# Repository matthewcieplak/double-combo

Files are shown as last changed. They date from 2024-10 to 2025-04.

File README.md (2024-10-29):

# AmpSim

## Author

Extralife Instruments

## Description

Amp sim module for Eurorack using Daisy Patch.

## Programming setup: 

Plug the daisy patch into the PC using USB.

Download and install Zadig. Run it to install the USB driver.

Build and program the device from source in VS code or use the daisy web uploader.

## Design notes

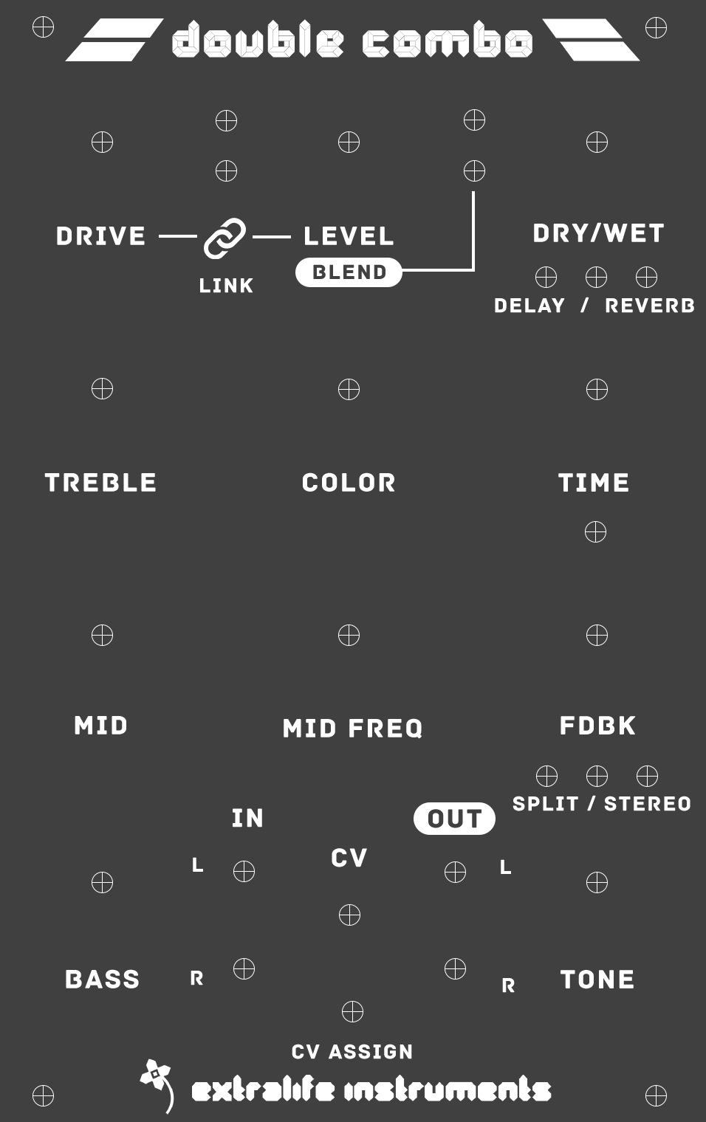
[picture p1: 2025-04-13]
graphics/double_combo.png

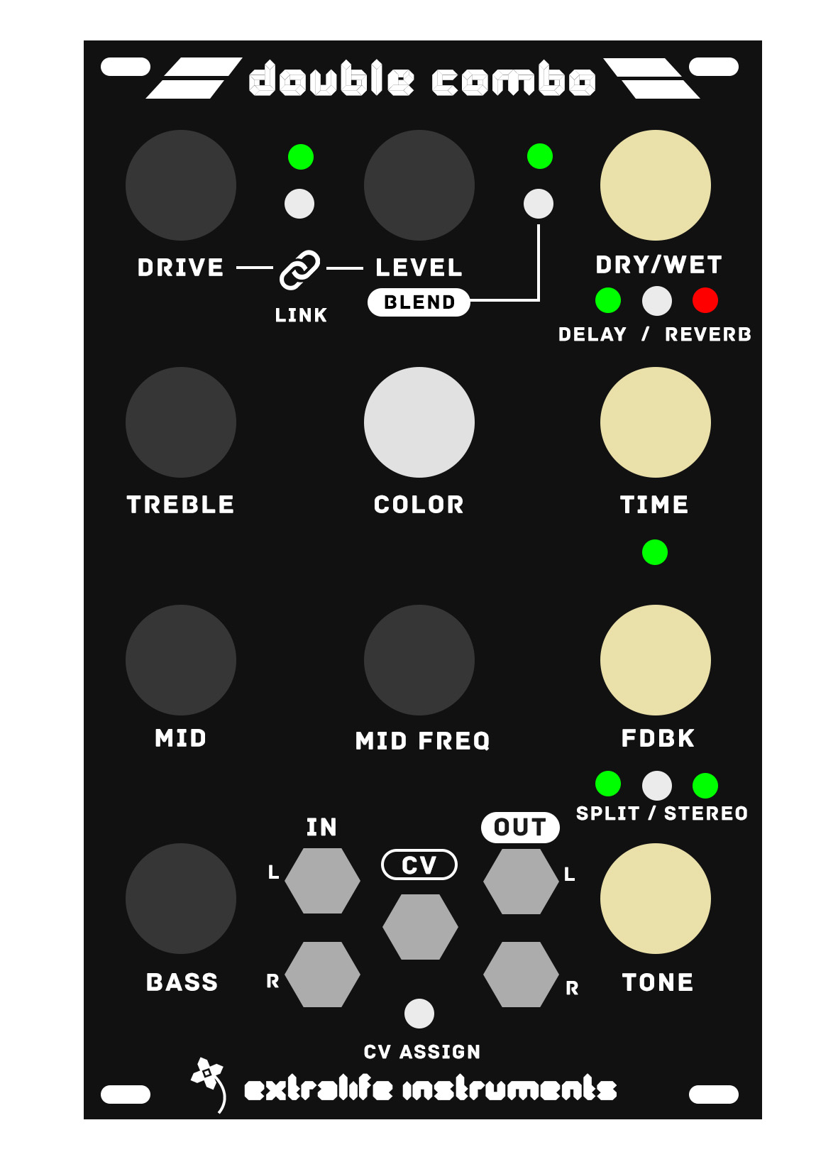
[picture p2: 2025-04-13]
graphics/front panel.jpg

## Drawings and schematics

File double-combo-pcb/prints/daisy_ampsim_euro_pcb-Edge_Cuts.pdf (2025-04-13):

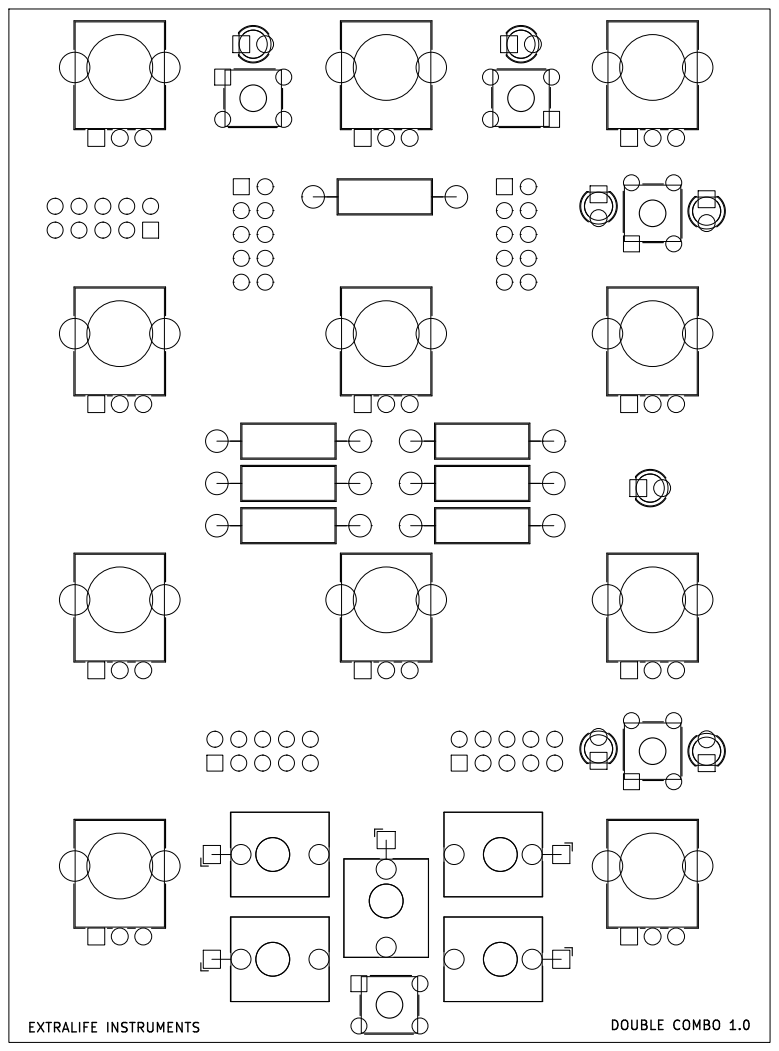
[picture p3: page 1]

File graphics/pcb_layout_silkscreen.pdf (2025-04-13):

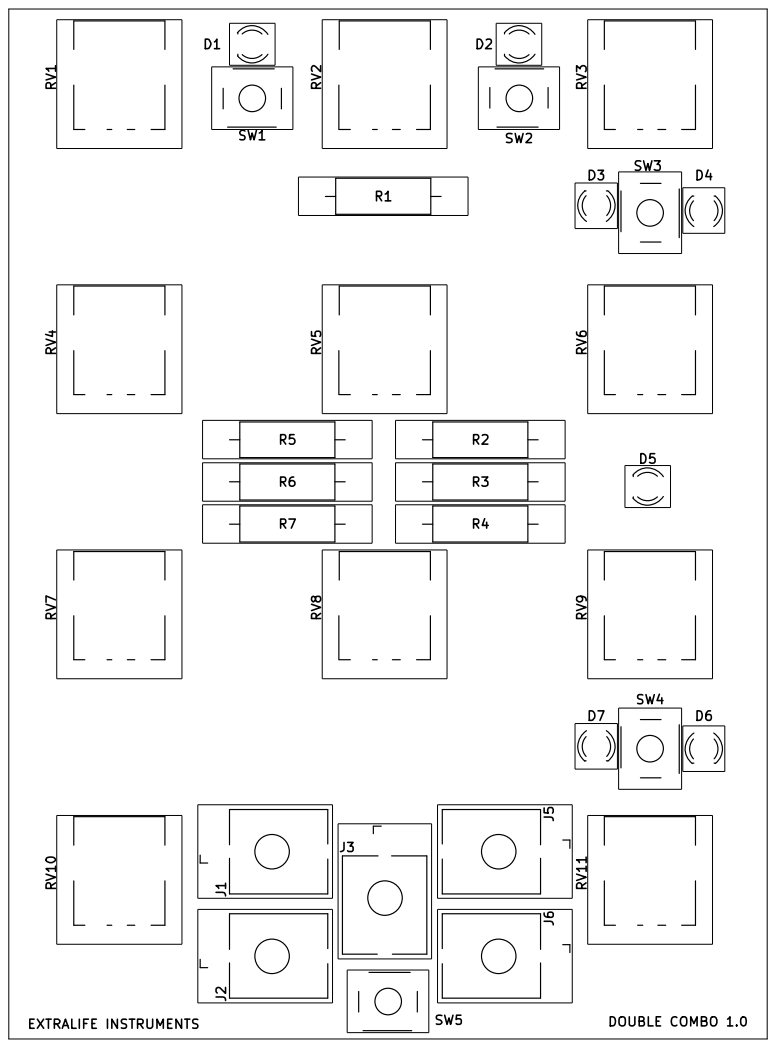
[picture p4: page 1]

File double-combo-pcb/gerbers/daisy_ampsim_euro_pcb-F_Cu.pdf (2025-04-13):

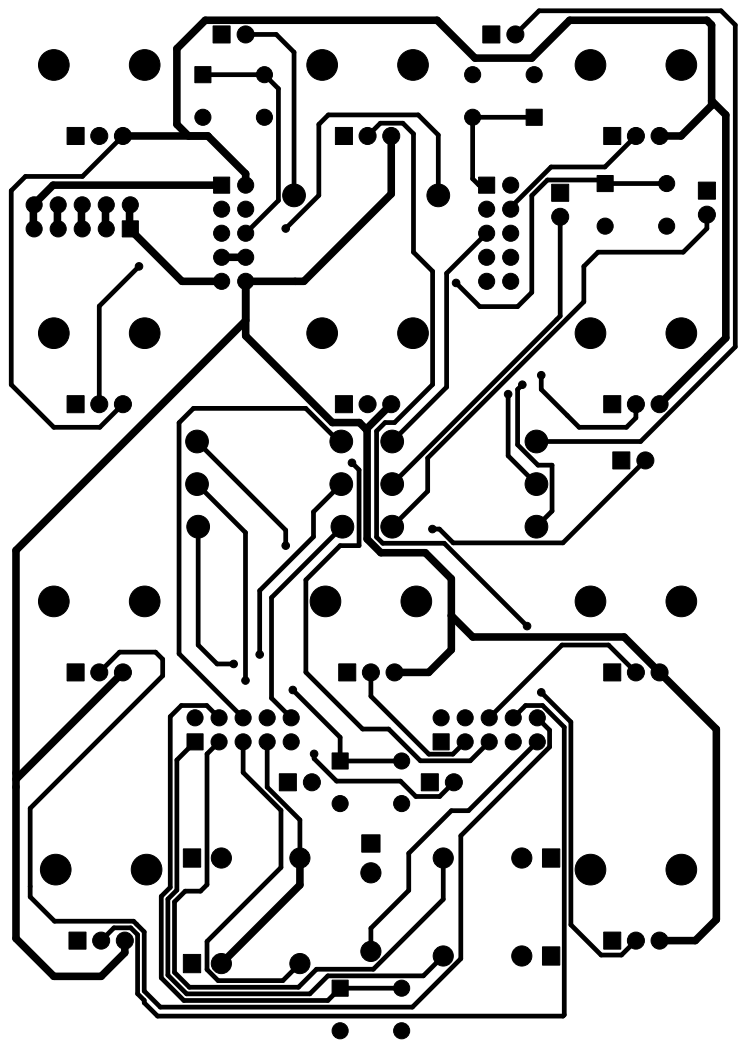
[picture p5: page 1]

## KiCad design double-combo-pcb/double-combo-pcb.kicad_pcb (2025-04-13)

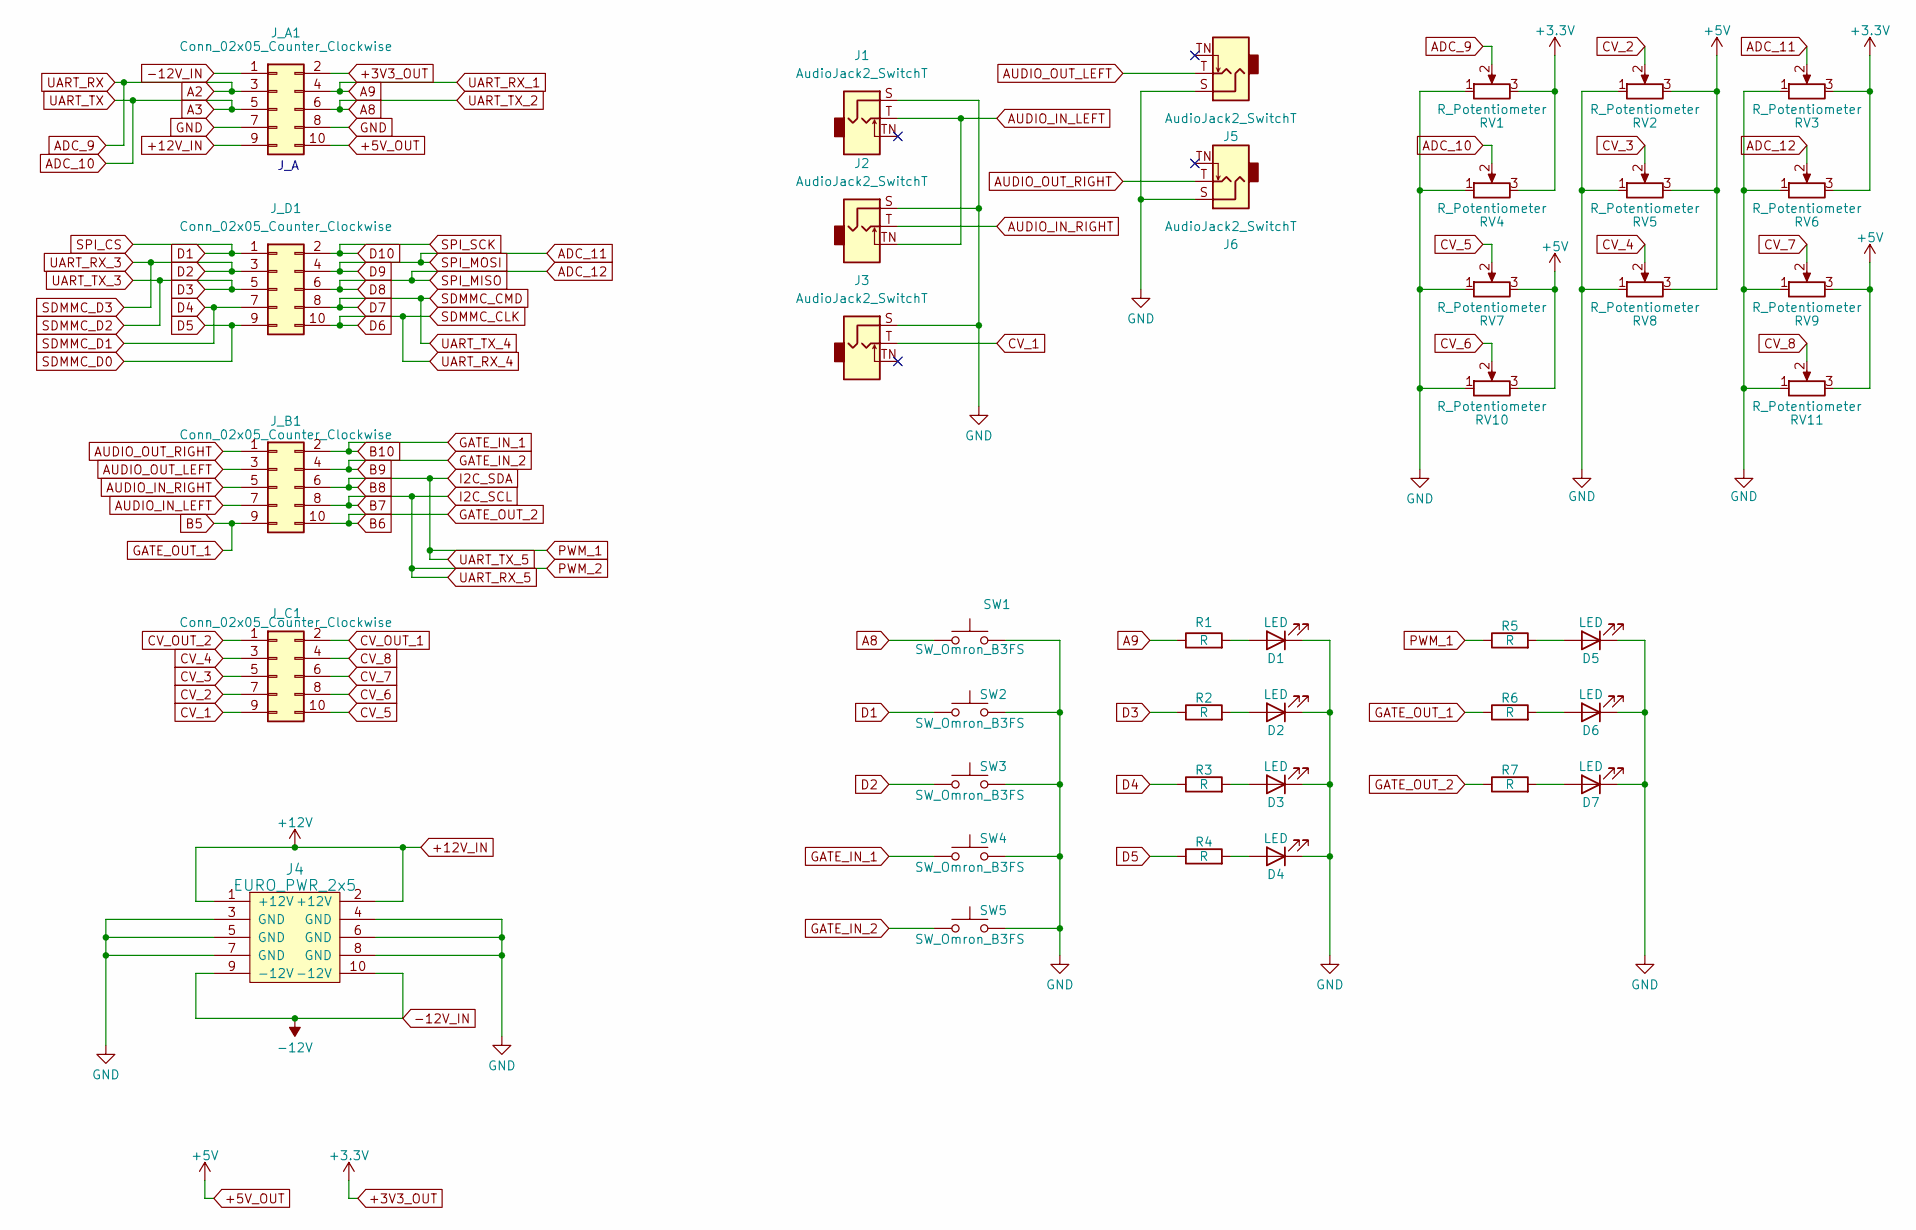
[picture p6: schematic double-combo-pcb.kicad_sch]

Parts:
D1, D2, D3, D4, D5, D6, D7: LED; LED_D3.0mm
J1, J2, J3, J5, J6: AudioJack2_SwitchT; Jack_3.5mm_QingPu_WQP-PJ398SM_Vertical_CircularHoles
J4: EURO_PWR_2x5; PinHeader_2x05_P2.54mm_Vertical
J_A1: Conn_02x05_Counter_Clockwise; PinSocket_2x05_P2.54mm_Vertical
J_B1: Conn_02x05_Counter_Clockwise; PinSocket_2x05_P2.54mm_Vertical
J_C1: Conn_02x05_Counter_Clockwise; PinSocket_2x05_P2.54mm_Vertical
J_D1: Conn_02x05_Counter_Clockwise; PinSocket_2x05_P2.54mm_Vertical
R1, R2, R3, R4, R5, R6, R7: R; R_Axial_DIN0411_L9.9mm_D3.6mm_P15.24mm_Horizontal
RV1, RV2, RV3, RV4, RV5, RV6, RV7, RV8, RV9, RV10, RV11: R_Potentiometer; Potentiometer_Alpha_RD901F-40-00D_Single_Vertical_CircularH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
SW1, SW2, SW3, SW4, SW5: SW_Omron_B3FS; SW_TH_Tactile_Omron_B3F-10xx

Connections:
+3V3_OUT: J_A1.2, RV1.3, RV3.3, RV4.3, RV6.3
+5V_OUT: J_A1.10, RV2.3, RV5.3, RV7.3, RV8.3, RV9.3, RV10.3, RV11.3
+12V_IN: J4.1 (+12V), J4.2 (+12V), J_A1.9
-12V_IN: J4.9 (-12V), J4.10 (-12V), J_A1.1
A2: J_A1.3, RV1.2
A3: J_A1.5, RV4.2
A8: J_A1.6, SW1.1
A9: J_A1.4, R1.1
ADC_11: J_D1.4, RV3.2
ADC_12: J_D1.6, RV6.2
AUDIO_IN_LEFT: J1.T, J2.TN, J_B1.7
AUDIO_IN_RIGHT: J2.T, J_B1.5
AUDIO_OUT_LEFT: J5.T, J_B1.3
AUDIO_OUT_RIGHT: J6.T, J_B1.1
B5: J_B1.9, R6.1
B6: J_B1.10, R7.1
B7: J_B1.8
B8: J_B1.6, R5.1
B9: J_B1.4, SW5.1
B10: J_B1.2, SW4.1
CV_1: J3.T, J_C1.9
CV_2: J_C1.7, RV2.2
CV_3: J_C1.5, RV5.2
CV_4: J_C1.3, RV8.2
CV_5: J_C1.10, RV7.2
CV_6: J_C1.8, RV10.2
CV_7: J_C1.6, RV9.2
CV_8: J_C1.4, RV11.2
CV_OUT_1: J_C1.2
CV_OUT_2: J_C1.1
D1: J_D1.1, SW2.1
D2: J_D1.3, SW3.1
D3: J_D1.5, R2.1
D4: J_D1.7, R3.1
D5: J_D1.9, R4.1
D6: J_D1.10
D7: J_D1.8
D10: J_D1.2
GND: D1.1 (K), D2.1 (K), D3.1 (K), D4.1 (K), D5.1 (K), D6.1 (K), D7.1 (K), J1.S, J2.S, J3.S, J4.3 (GND), J4.4 (GND), J4.5 (GND), J4.6 (GND), J4.7 (GND), J4.8 (GND), J5.S, J6.S, J_A1.7, J_A1.8, RV1.1, RV2.1, RV3.1, RV4.1, RV5.1, RV6.1, RV7.1, RV8.1, RV9.1, RV10.1, RV11.1, SW1.2, SW2.2, SW3.2, SW4.2, SW5.2
unnamed: D1.2 (A), R1.2
unnamed: D2.2 (A), R2.2
unnamed: D3.2 (A), R3.2
unnamed: D4.2 (A), R4.2
unnamed: D5.2 (A), R5.2
unnamed: D6.2 (A), R6.2
unnamed: D7.2 (A), R7.2

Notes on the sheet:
J_A

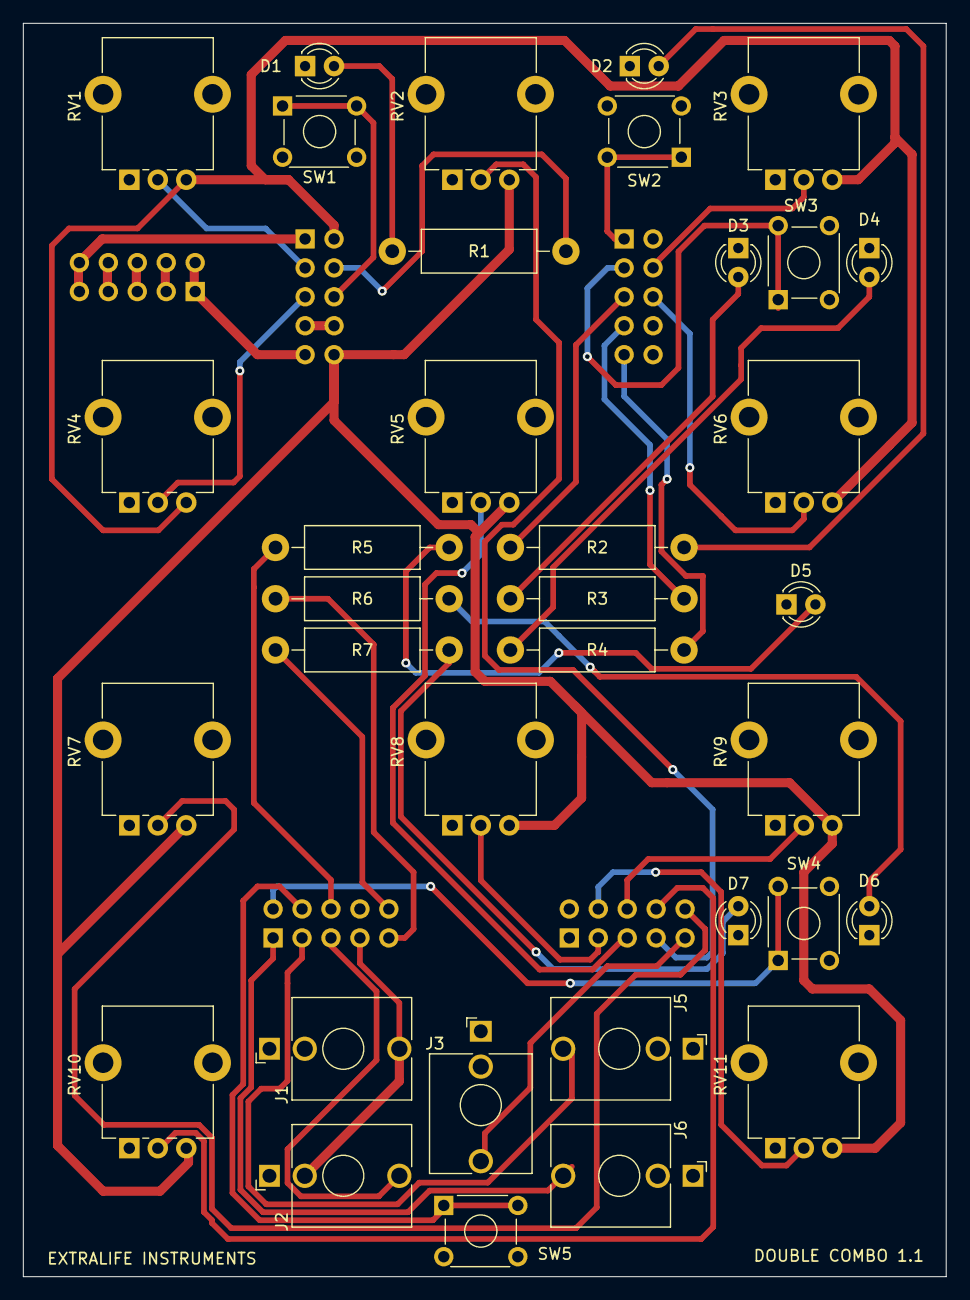
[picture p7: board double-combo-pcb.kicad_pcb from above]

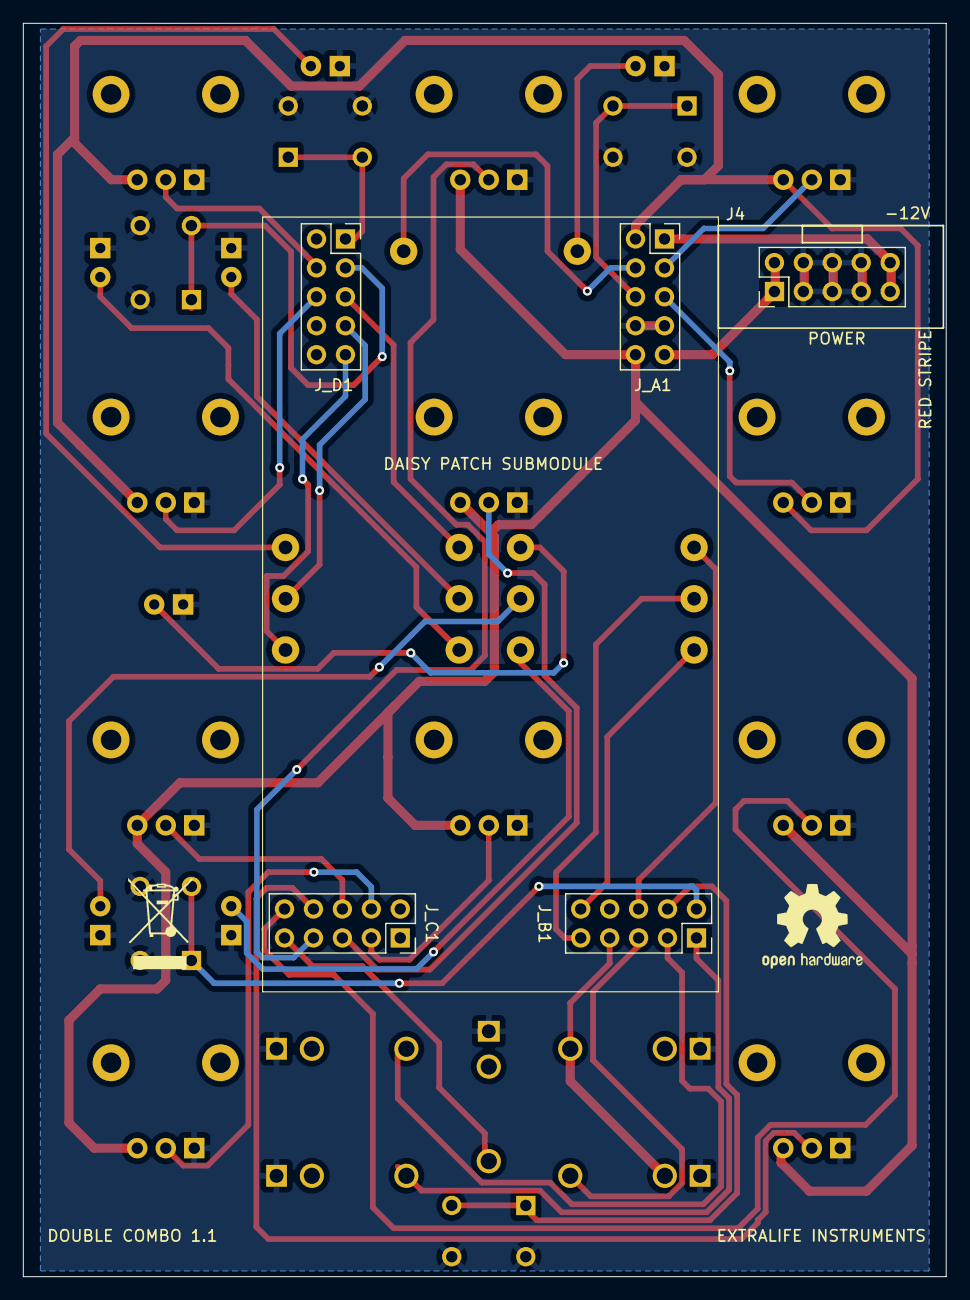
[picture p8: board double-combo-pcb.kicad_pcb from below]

Board: 2 copper layers, 81.0 x 110.0 mm, 40 parts (5 on the bottom side), 40 nets.

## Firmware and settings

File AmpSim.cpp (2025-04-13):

// #include "daisy_seed.h"

/** Our hardware board class handles the interface to the actual DaisyPatchSM
 * hardware. */
#include "daisy_patch_sm.h"
#include "daisysp.h"
// #include "onepole.h"

#define BUTTON_SAMPLE_RATE 100
#define TIME_LED_BRIGHTNESS 0.6

// Set max delay time to 0.75 of samplerate.
#define MAX_DELAY static_cast<size_t>(48000 * 2.5f)

using namespace daisy;
// using namespace daisy::seed;
using namespace patch_sm;

using namespace daisysp;

// DaisySeed hw;
DaisyPatchSM hw;


static OnePole AmpLowPass;
static Svf BassLowPass;
static Svf    AmpBandPass;
static Svf    TrebleBandPass;
static Svf    MidBandPass;
static Overdrive Drive;

// static ReverbSc rev;
static DelayLine<float, MAX_DELAY> DSY_SDRAM_BSS dlyl;
static DelayLine<float, MAX_DELAY> DSY_SDRAM_BSS dlyr;

float knob_gain, knob_volume, knob_treble, knob_mid_gain, knob_bass, knob_color, knob_fx_dry_wet, knob_fx_feedback, knob_fx_time, knob_fx_tone, ctrl_blend;
int16_t  knob_mid_freq;

Switch button_link, button_blend, button_fx; // button_stereo, button_cv;

GPIO led_link, led_blend, led_delay, led_reverb, led_split, led_stereo, led_time; //TODO reverse orientation of split and stereo LEDs, rotate time led to match others

Led led_time_pwm;


GateIn button_stereo, button_cv;

Oscillator time_osc;

bool state_link, state_blend, state_fx, state_stereo, state_cv, state_stereo_button, state_cv_button;

float maxDelay, currentDelay, feedback, delayTarget, cutoff, drive_compensation;


void GetReverbSample(float &inl, float &inr);
void GetDelaySample(float &inl, float &inr);
void process_eq_mid(float &f1, float &f2);
void process_eq_bass(float &f1, float &f2);
void process_eq_treble(float &f1, float &f2);
void process_eq_color(float &f1, float &f2);
void process_drive(float &f1, float &f2);
void process_amp_sim(float &f1, float &f2);
void process_fx(float &f1, float &f2);


void AudioCallback(AudioHandle::InputBuffer in, AudioHandle::OutputBuffer out, size_t size)
{
	for (size_t i = 0; i < size; i++)
	{
		float f1, f2, f3, f4;

		f1 = in[0][i];
		f2 = in[1][i];

		process_eq_mid(f1, f2);

		f3 = f1;
		f4 = f2;

		process_drive(f1, f2);

		process_amp_sim(f1, f2);

		f1 = ctrl_blend * (f1 * drive_compensation) + ((1.0-ctrl_blend) * f3); //blend in clean signal
		if (state_stereo)
			f2 = ctrl_blend * (f2 * drive_compensation) + ((1.0-ctrl_blend) * f4);

		process_eq_treble(f1, f2);

		process_eq_bass(f1, f2);

		process_eq_color(f1, f2);
		

		// f1 = f1 * knob_volume * 1.2;
		// if (!state_stereo) 
		// 	f2 = f2 * knob_volume * 1.2;



		// uncomment for audio passthrough test
		// out[0][i] = in[0][i];
		// out[1][i] = in[1][i];

		process_fx(f1, f2);


		out[0][i] = f1;
		out[1][i] = f2;
	}
}

void process_eq_mid(float &f1, float &f2){
	MidBandPass.SetFreq(knob_mid_freq);
	MidBandPass.SetRes(abs(knob_mid_gain) * 0.5);
	MidBandPass.Process(f1);

	f1 = MidBandPass.Band() * knob_mid_gain * 2.0 + f1; //add bandpass to dry signal in +/- to act as peak or dip
	if (state_stereo) {
		MidBandPass.Process(f2);
		f2 = MidBandPass.Band() * knob_mid_gain * 2.0 + f2; //add bandpass to dry signal in +/- to act as peak or dip
	}
}

void process_eq_bass(float &f1, float &f2){
	BassLowPass.SetRes(0.2);
	BassLowPass.SetFreq(300); //(bassValue + 0.5) * 10000);
	BassLowPass.Process(f1);
	f1 = BassLowPass.Low() * knob_bass * 2.0 + f1;
	if (state_stereo) {
		BassLowPass.Process(f2);
		f2 = BassLowPass.Low() * knob_bass * 2.0 + f2;
	}
	// f2 = (f2 * bassValue);// - f1;
}

void process_eq_treble(float &f1, float &f2){
	TrebleBandPass.SetRes(0.2);
	TrebleBandPass.SetFreq(3500);
	TrebleBandPass.Process(f1);
	f1 = (TrebleBandPass.High() * knob_treble * 2.0) + f1;
	if (state_stereo) {
		TrebleBandPass.Process(f2);
		f2 = (TrebleBandPass.High() * knob_treble * 2.0) + f2;
	}
}


void process_amp_sim(float &f1, float &f2){
	// AmpLowPass.SetRes(0.2);
	AmpLowPass.SetFrequency(4100); //(bassValue + 0.5) * 10000);
	f1 = AmpLowPass.Process(f1);
	if (state_stereo) 
		f2 = AmpLowPass.Process(f2);
	

	AmpBandPass.SetRes(0.05);
	AmpBandPass.SetDrive(0.2);
	AmpBandPass.SetFreq(680);
	AmpBandPass.Process(f1);
	f1 = AmpBandPass.Band() * -0.8 + f1;
	if (state_stereo) {
		AmpBandPass.Process(f2);
		f2 = AmpBandPass.Band() * -0.8 + f2;
	}
	// AmpBandPass.Process(f2);
		// f1 = AmpBandPass.Band() * -1.0 + f2;
		// f2 = AmpLowPass.Process(f1);
}

void process_eq_color(float &f1, float &f2){

}

void process_drive(float &f1, float &f2){
	Drive.SetDrive(knob_gain*0.95 + 0.05);
	drive_compensation = (2.0-knob_gain) * 0.5;
	f1 = Drive.Process(f1);
	if (state_stereo) 
		f2 = Drive.Process(f2);
}

void process_fx(float &f1, float &f2) {
	float verbl = f1 * knob_fx_dry_wet;
	float verbr = f2 * knob_fx_dry_wet;
	
	if (!state_stereo)
		f1 = f1 * (1.0 - knob_fx_dry_wet*knob_fx_dry_wet);
	f2 = f2 * (1.0 - knob_fx_dry_wet*knob_fx_dry_wet);
	
	if (state_fx) {		
		GetReverbSample(verbl, verbr);
	} else { 
		GetDelaySample(verbl, verbr);
	}

	if (!state_stereo)
		f1 += verbl;
	f2 += verbr;
}

void setFilterConstants(float sample_rate);

void readKnobs();
void readButtons();

int main(void)
{
	hw.Init();

	//initialize buttons
	button_link.Init(hw.A8, BUTTON_SAMPLE_RATE);
	button_blend.Init(hw.D1, BUTTON_SAMPLE_RATE);
	button_fx.Init(hw.D2, BUTTON_SAMPLE_RATE);
	button_stereo.Init(hw.B10, BUTTON_SAMPLE_RATE);  //gate_in_1
	button_cv.Init(hw.B9, BUTTON_SAMPLE_RATE); //gate_in_2

	//initialize LEDs
	led_link.Init(hw.A9, GPIO::Mode::OUTPUT);
	led_blend.Init(hw.D3, GPIO::Mode::OUTPUT);
	led_delay.Init(hw.D4, GPIO::Mode::OUTPUT);
	led_reverb.Init(hw.D5, GPIO::Mode::OUTPUT);
	led_split.Init(hw.B5, GPIO::Mode::OUTPUT);
	led_stereo.Init(hw.B6, GPIO::Mode::OUTPUT);
	// led_time.Init(hw.B8, GPIO::Mode::OUTPUT);
	led_time_pwm.Init(hw.B8, false, 1000.0f);
	led_time_pwm.Set(127.0);

	//set initial fx/split state
	led_delay.Write(true);
	led_stereo.Write(true);
	state_fx = false;
	state_stereo = true;
	ctrl_blend = 1.0;

	// Set up the LED PWM oscillator
	time_osc.Init(hw.AudioSampleRate());
	time_osc.SetWaveform(Oscillator::WAVE_SIN);
	time_osc.SetFreq(1.0);

	// Start the ADC
	hw.adc.Start();

	// Initialize audio params
	setFilterConstants(hw.AudioSampleRate());
	hw.SetAudioBlockSize(4); // number of samples handled per callback
	hw.SetAudioSampleRate(SaiHandle::Config::SampleRate::SAI_48KHZ);
	hw.StartAudio(AudioCallback);
	


	while(1) {
		hw.ProcessAllControls();
		readKnobs();
		readButtons();		
		led_time_pwm.Update();
	}
}

float led_brightness = 0;

void readButtons(){
	button_blend.Debounce();
	if (button_blend.RisingEdge()) {
		state_blend = !state_blend;
		led_blend.Write(state_blend);
	}

	button_link.Debounce();
	if (button_link.RisingEdge()) {
		state_link = !state_link;
		led_link.Write(state_link);
	}

	button_fx.Debounce();
	if (button_fx.RisingEdge()) {
		state_fx = !state_fx; //True = delay active
		led_delay.Write(!state_fx);
		led_reverb.Write(state_fx);
		// led_time.Write(state_stereo);// todo convert to pwm pulse
	}	

	//button_stereo and button_cv use gate_in object and need special handling for toggle and state
	if ((button_stereo.State() && state_stereo_button == false)) {
		state_stereo_button = button_stereo.State();
		if (state_stereo_button == true) {
			state_stereo = !state_stereo;
			led_stereo.Write(state_stereo);
			led_split.Write(!state_stereo);
		}
	}
	state_stereo_button = button_stereo.State();



	if (button_cv.State() != state_cv_button) {
		state_cv_button = button_cv.State();
		state_cv = state_cv_button;
		led_stereo.Write(state_cv);
	}
}


void readKnobs(){
	hw.ProcessAnalogControls();
	hw.ProcessDigitalControls();

	knob_gain     = hw.GetAdcValue(ADC_9); // gainValue    = hw.adc.GetFloat(gainKnob);

	if (state_blend) {
		ctrl_blend  = hw.GetAdcValue(CV_2); //.5; //hw.adc.GetFloat(volumeKnob);
	} else {
		knob_volume = hw.GetAdcValue(CV_2); //.5; //hw.adc.GetFloat(volumeKnob);
	}
	
	knob_treble   = hw.GetAdcValue(ADC_10) - 0.25; //hw.adc.GetFloat(trebleKnob) - 0.25;
	knob_mid_freq = hw.GetAdcValue(CV_4) * 4000 + 170; //hw.adc.GetFloat(midFreqKnob) * 4000.0 + 170;
	knob_mid_gain = hw.GetAdcValue(CV_5) - 0.25; //hw.adc.GetFloat(midGainKnob) - 0.25;
	knob_bass     = hw.GetAdcValue(CV_6) - 0.25; //hw.adc.GetFloat(bassKnob) - 0.25;
	knob_color    = hw.GetAdcValue(CV_3);

	knob_fx_dry_wet  = hw.GetAdcValue(ADC_11);
	knob_fx_time     = hw.GetAdcValue(ADC_12);
	knob_fx_feedback = hw.GetAdcValue(CV_7);
	knob_fx_tone     = hw.GetAdcValue(CV_8);

	currentDelay = maxDelay * knob_fx_time;

	time_osc.SetFreq(3.0 * (1.0 - knob_fx_time) + 0.1);
	
	led_time_pwm.Set((time_osc.Process() + 0.6) * TIME_LED_BRIGHTNESS);
}

void setFilterConstants(float sample_rate){
	AmpLowPass.SetFrequency(2800);
	// AmpLowPass.SetRes(0.1);
	AmpLowPass.Init(); //sample_rate);
	// AmpLowPass.SetFilterMode(FilterMode);

	AmpBandPass.SetDrive(0.1);
	AmpBandPass.SetFreq(680);
	AmpBandPass.SetRes(0.1);
	AmpBandPass.Init(sample_rate);

	TrebleBandPass.SetFreq(3500);
	TrebleBandPass.SetDrive(0.2);
	TrebleBandPass.SetRes(0.2);
	TrebleBandPass.Init(sample_rate);

	BassLowPass.Init(sample_rate);
	BassLowPass.SetFreq(300);
	BassLowPass.SetRes(0.1);


	MidBandPass.SetFreq(1000);
	MidBandPass.SetDrive(0.2);
	MidBandPass.SetRes(0.3);
	MidBandPass.Init(sample_rate);

	Drive.SetDrive(0.2);
	Drive.Init();

	// rev.Init(sample_rate);
    dlyl.Init();
    dlyr.Init();

    //reverb parameters
    // rev.SetLpFreq(18000.0f);
    // rev.SetFeedback(0.85f);

    //delay parameters
    maxDelay = delayTarget = sample_rate * 0.75f;
	currentDelay = maxDelay;
    dlyl.SetDelay(currentDelay+ 10);
    dlyr.SetDelay(currentDelay+ 10);
}

void GetReverbSample(float &inl, float &inr)
{
    // rev.Process(inl, inr, &inl, &inr);
}

void GetDelaySample(float &inl, float &inr)
{
    fonepole(currentDelay, delayTarget, .00007f);
    dlyl.SetDelay(currentDelay);
    dlyr.SetDelay(currentDelay);
    float outl = dlyl.Read();
    float outr = dlyr.Read();
	

    dlyl.Write((knob_fx_feedback * outl) + inl);
    inl = outl + inl; //(knob_fx_feedback * outl) + ((1.0f - knob_fx_feedback) * inl);

    dlyr.Write((knob_fx_feedback * outr) + inr);
    inr = outr + inr; //(knob_fx_feedback * outr) + ((1.0f - knob_fx_feedback) * inr);
}

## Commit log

2025-04-13 Adding KiCad files
    [double-combo-pcb-B_Cu.gbr, double-combo-pcb-B_Fab.gbr, double-combo-pcb-B_Mask.gbr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]
2025-04-13 fix: correcting delay feedback logic
    [AmpSim.cpp]
